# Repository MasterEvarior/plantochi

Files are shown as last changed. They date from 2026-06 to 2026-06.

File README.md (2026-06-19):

# Plantochi

> [!IMPORTANT]
> This project was done during a school workshop, so it will not be maintained.

A [Tamagotchi](https://de.wikipedia.org/wiki/Tamagotchi) but for your plants!

See the guide [here](https://masterevarior.github.io/plantochi/).

## Development

### Git hooks

The repository ships two git hooks under `.githooks/`:

- `commit-msg` — validates that commit messages conform to the Conventional
  Commit format.
- `pre-commit` — runs `nix flake check` before each commit.

When you enter the dev shell (`nix develop`), the hooks are wired up
automatically via `git config core.hooksPath .githooks/`.

### direnv

If you have [direnv](https://direnv.net/) installed, the dev shell is loaded
automatically when you enter the directory:

```sh
direnv allow
```

### Commands

Run to see a list of all available commands:

```shell
just
```

## AI Disclaimer

OpenCode BigPickle was used to generate an initial version of this `README.md` and some parts of the documentation.

## License

MIT

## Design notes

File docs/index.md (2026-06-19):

# Plantochi

Plantochi is a [Tamagotchi](https://de.wikipedia.org/wiki/Tamatchi) but for your plants!

- [Guide](guide.md){step}
- [Journey](journey.md){step}

Plantochi shows with unique facial expression the current crucial way that their owner lets them die with.
An example is linked below where the plan is thirsty and too hot.



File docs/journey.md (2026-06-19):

# Journey

## Day 1

On day 1, we only had a short brainstorming session. See the results below.

### Brainstorming

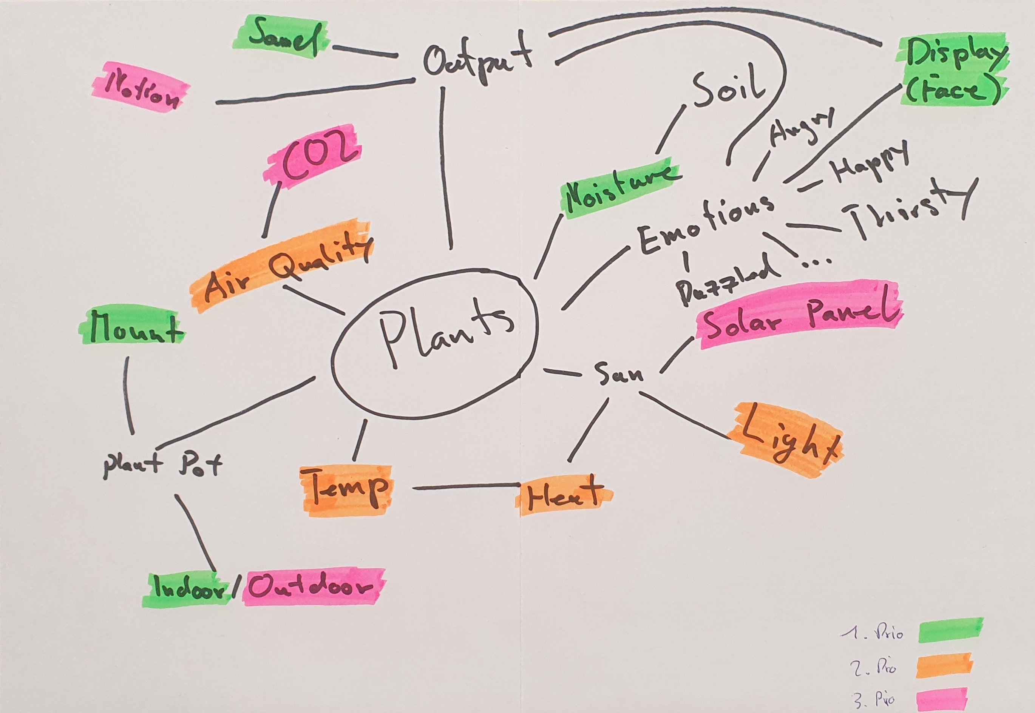
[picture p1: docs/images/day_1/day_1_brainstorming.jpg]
A piece of paper with brainstorming arround plants


From a first brainstorming session, we identified different things, with different priorities.
We decided on three priorities, with the following features:

| Priority (High to Low) | Features |
|-|-|
| 1 | Display and sound as output. Soil moisture sensor. Indoor only. |
| 2 | Air, temperature, light sensors in addition. |
| 3 | Motion (e.g. vibrating) as another way to get attention. A solar panel as energy source. Also rated for outdoor use.|

## Day 2

Creation of the first proof of concept (PoC) and prototypes. We also thought about how we can and should display the values to a user.

### Prototype Box

The first cardboard prototype was essentially a big box, with two hooks to put it onto a flower pot. The MCU (microcontroller unit) is placed towards the bottom so that the charging port can be placed below the box, together with the speaker which is hidden there. The display, light sensor and cables to extend to the soil moisture sensor are placed on the top.

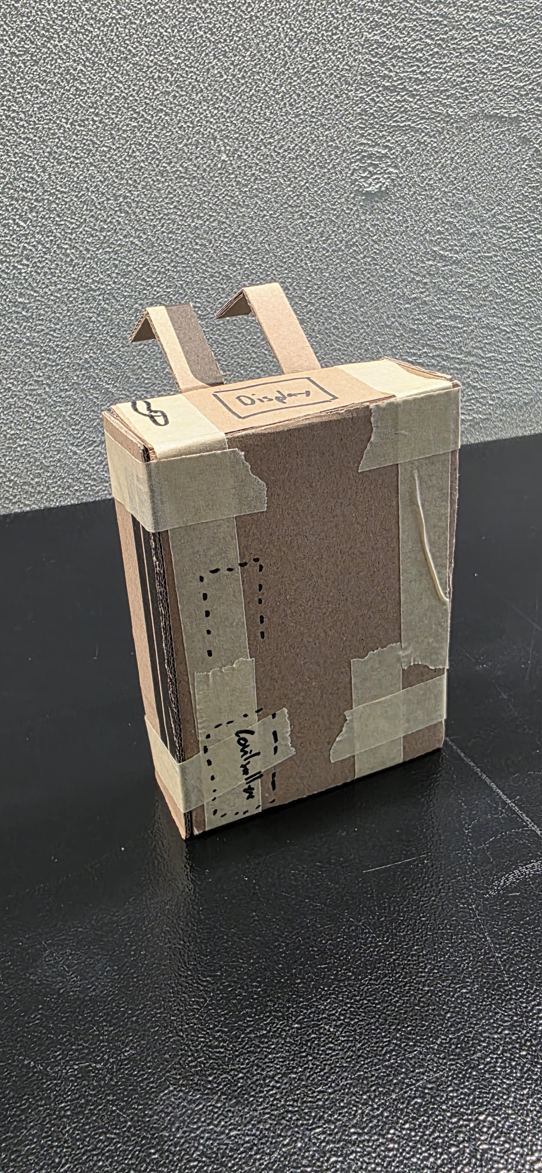
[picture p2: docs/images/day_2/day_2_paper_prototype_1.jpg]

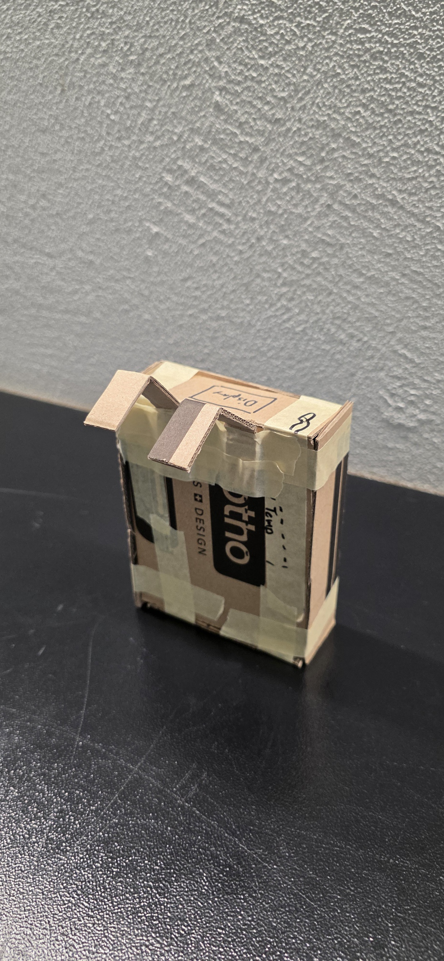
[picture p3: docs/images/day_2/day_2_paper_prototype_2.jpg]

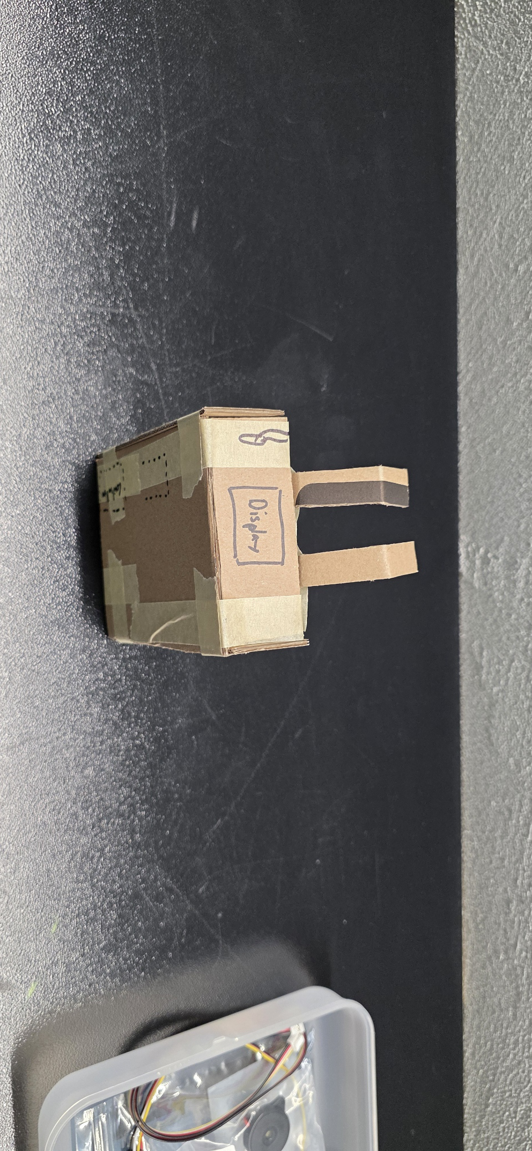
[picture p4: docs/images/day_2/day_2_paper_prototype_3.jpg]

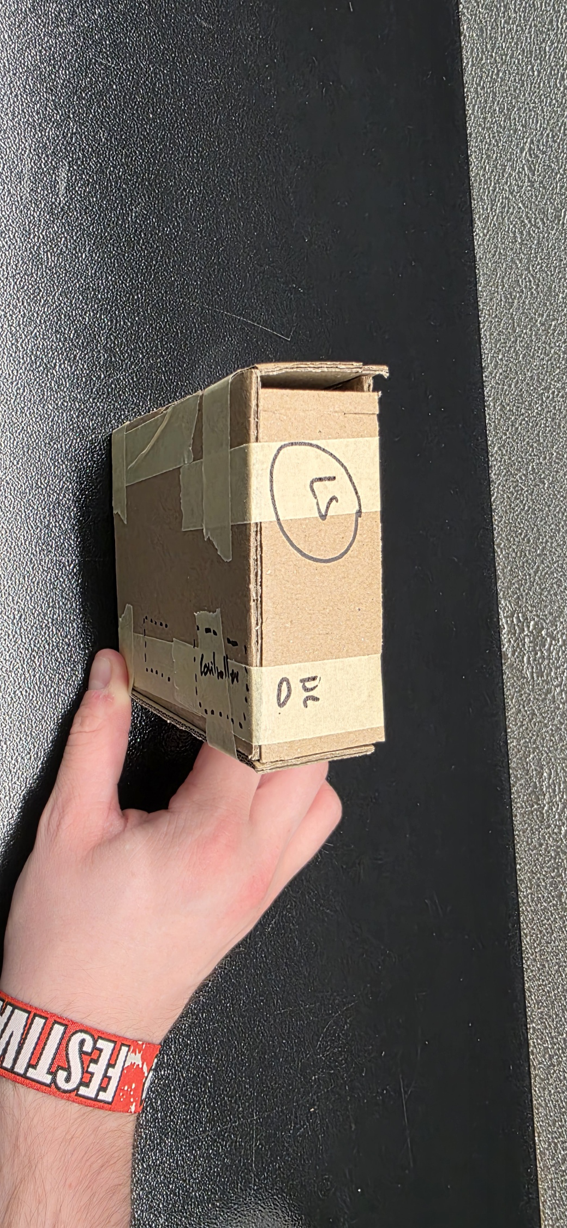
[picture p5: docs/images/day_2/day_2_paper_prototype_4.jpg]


### UI (Emotions)

Emotions are used to communicate with the user. Emotions like too bright or dark are naturally exclusive with each other. The following emotions are possible:

- Thirsty or waterlogged
- Too bright or dark
- Too hot or cold

The OLED displaying a face will be used to express the emotions.

| Sensors | Display |
|---|---|
| Thirsty | Open Mouth |
| Waterlogged | Sad Mouth |
| Bright | Squinted Eyes or Sunglasses |
| Dark | Big Eyes with huge pupils |
| Hot | Waves (like the ones on heaters) |
| Cold | Snowflake |

If two emotions concur at the same time, or it is "Thirsty", a piezo will be activated to cause sleepless nights.

### PoC

### Code

You can see the code for the first prototype [here](../code/poc_1/poc_1.ino).

#### Sketch of the PoC

A first sketch of the prototype is displayed below.
It is used to get some sense of what components we need and a bit on how they are supposed to be wired up.

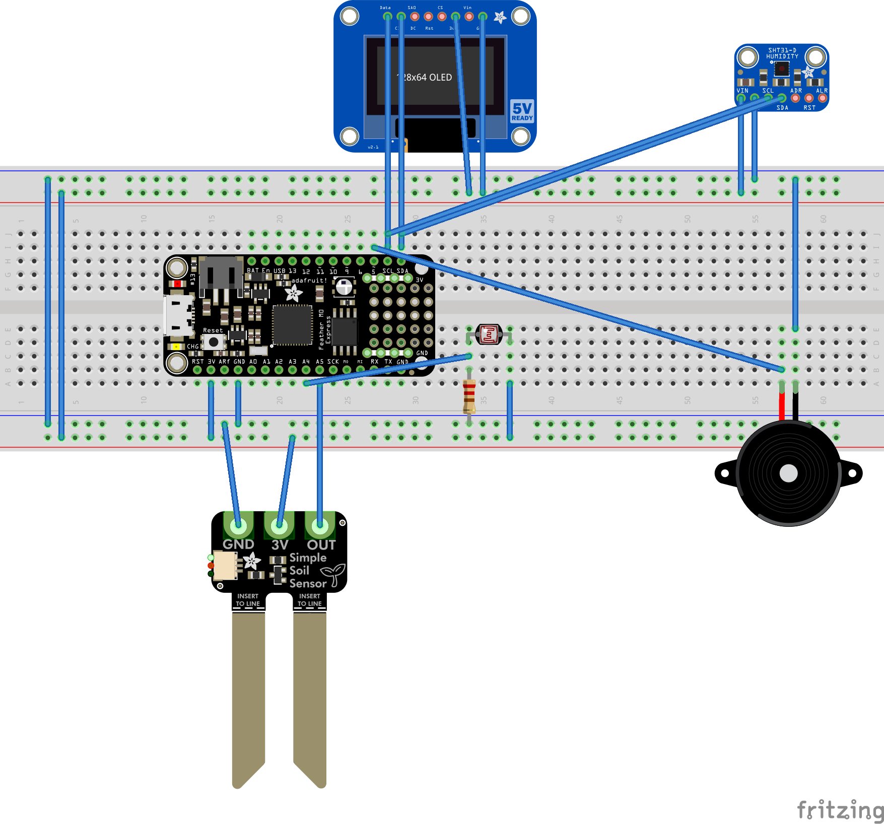
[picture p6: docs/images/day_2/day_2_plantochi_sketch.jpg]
Breadboard sketch of platochi in Fritzing


As there are about three craploads of components, we went on an expedition with our shovels and pickaxes and selected the components according to our plan.

#### Pinout

Description and more details: [https://learn.adafruit.com/adafruit-feather-m4-express-atsamd51/pinouts](https://learn.adafruit.com/adafruit-feather-m4-express-atsamd51/pinouts)

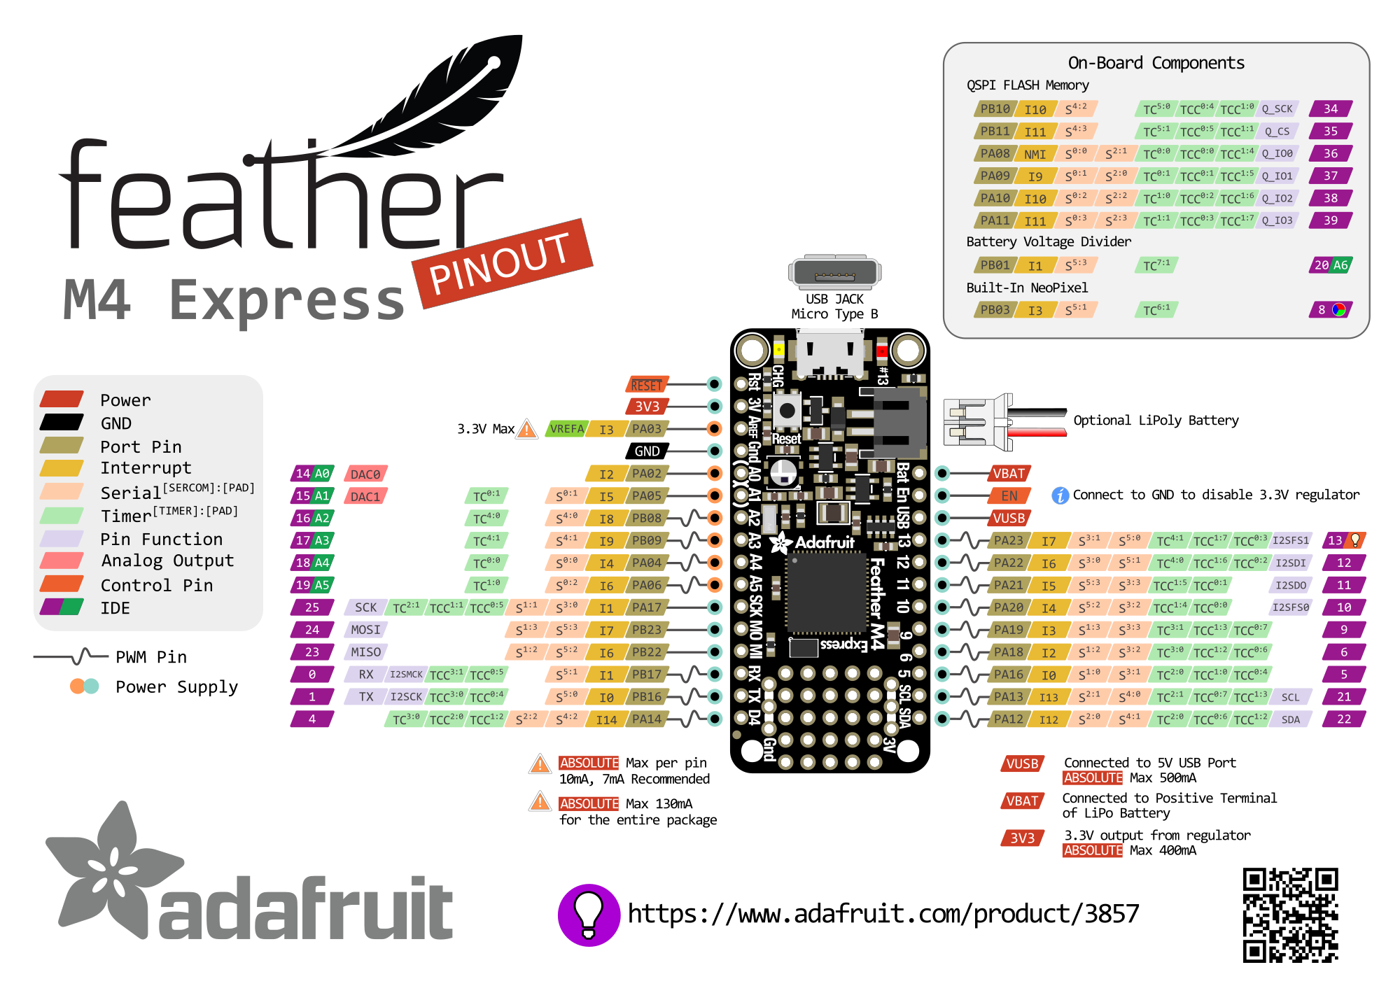
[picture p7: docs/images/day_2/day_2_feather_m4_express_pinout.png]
Pinout schematic for Feather M4 Express


## Day 3

Today was mostly spent finishing up the code and designing the enclosure.

### Code

The code was split in multiple files to make it *somewhat* more manageable. This brought the core loop to look like this:

```{.c}
void loop(void) {
  int badStates = 0;
  bool isThirsty = 0;

  Symbol symbol = Symbol::NONE;
  Eyes eyes = Eyes::NORMAL;
  Mouth mouth = Mouth::HAPPY;

  float light = readSensor(LIGHT);
  if(light > L_THRESHOLD_HIGH){
    eyes = Eyes::SQUINT;
    badStates++;
  } else if (light < L_THRESHOLD_LOW){
    eyes = Eyes::BIG;
    badStates++;
  } else {
    eyes = Eyes::NORMAL;
  }

  float airTemp = readSensor(AIR_TEMPERATURE);
  if(airTemp > T_THRESHOLD_HIGH){
    badStates++;
    symbol = Symbol::HEAT;
  } else if (airTemp < T_THRESHOLD_LOW){
    badStates++;
    symbol = Symbol::COLD;
  } else {
    symbol = Symbol::NONE;
  }

  // The value of the moisture sensor decreases
  // as the moisture increases
  float soilMoisture = readSensor(SOIL_MOISTURE);
  if(soilMoisture > M_THRESHOLD_HIGH){
    badStates++;
    isThirsty = 1;
    mouth = Mouth::OPEN;
  } else if (soilMoisture < M_THRESHOLD_LOW){
    badStates++;
    mouth = Mouth::SAD;
  } else {
    mouth = Mouth::HAPPY;
  }

  displayClear();
  displaySmiley(symbol, eyes, mouth);
  String text = getText(badStates);
  displayText(text.c_str());
  displayShow();

  if((isThirsty || badStates > 1) && !isBeeping){
    startBeep();
  } else {
    stopBeep();
  }

  updateBeep();

  // Cooldown
  delay(1500);
}
```

You can see the entire code under `/code/prod/`.

### Enclosure

The plantochi should be usable for all kinds of plants.
Some of these plants generate produce.
The PLA that is used in the schools’ 3D-printers, is not particularly food safe.
Therefore, wood was used for the box which is laser cut from sheets.

V1 schema for box

After laser cutting the box was assembled and held together by strong willpower, prayers and some tape.

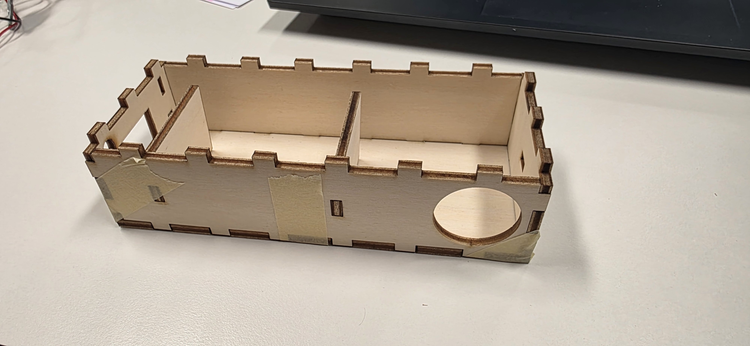
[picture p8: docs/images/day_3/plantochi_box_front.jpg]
Assembled box front

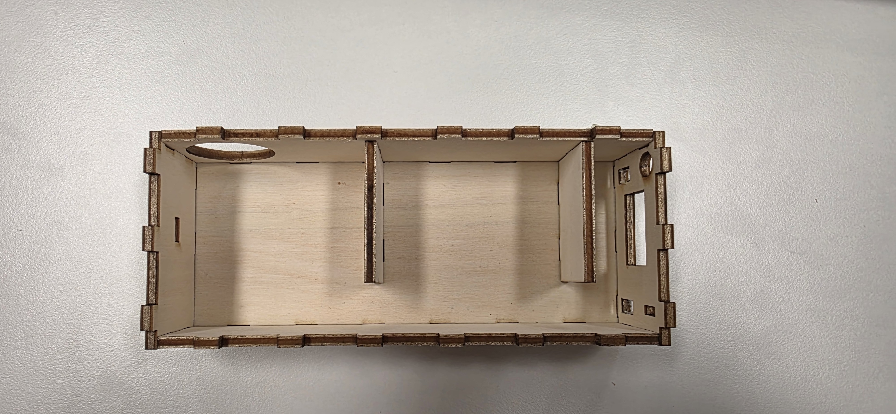
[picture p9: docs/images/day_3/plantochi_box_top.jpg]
Assembled box top


Some details were noticed when putting the components into the box:

- The cable for the display is very short and needs to reach very far
  - Moving the display slot a bit over
  - Switching the orientation for the box so that the display points the right way (parts of the display are blue and 
    yellow and this needs to face the right direction).
- Increase the size for the soil moisture sensor cable.
- Decrease the size for the LDR sensor (must have been drunk while measuring that).
- Adding a little hole in the wall for the battery.
- Increasing the size for the charging cable (those suckers are huge).

V2 schema for box

After planning all the details and creating different mount options (based on flower pot sizes), the **Next Gen Box 2.0** 
is released.
The **Next Gen Box 2.0** comes without any problems and can actually be used with the selected components.
Some wood glue and tape later, it is assembled and ready for tomorrow's hot glue day, where we make fit everything in 
the box.

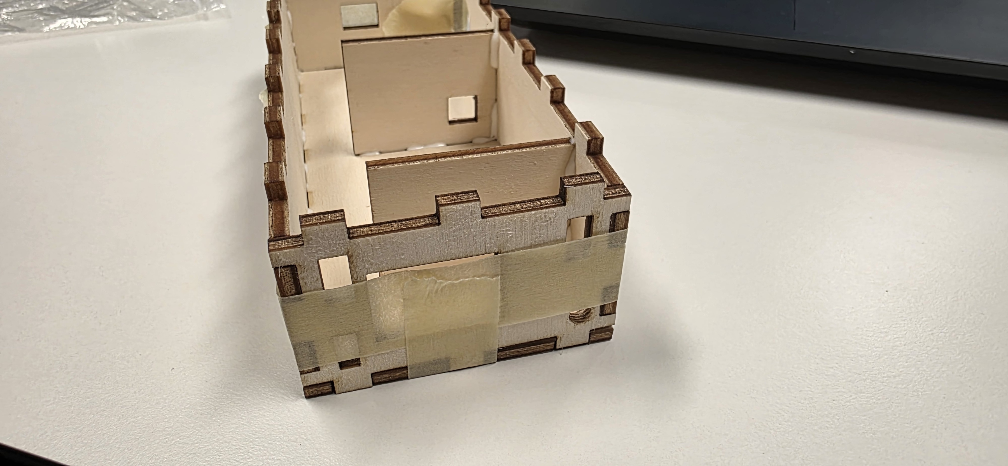
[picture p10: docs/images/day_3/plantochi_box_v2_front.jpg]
Assembled box v2 front

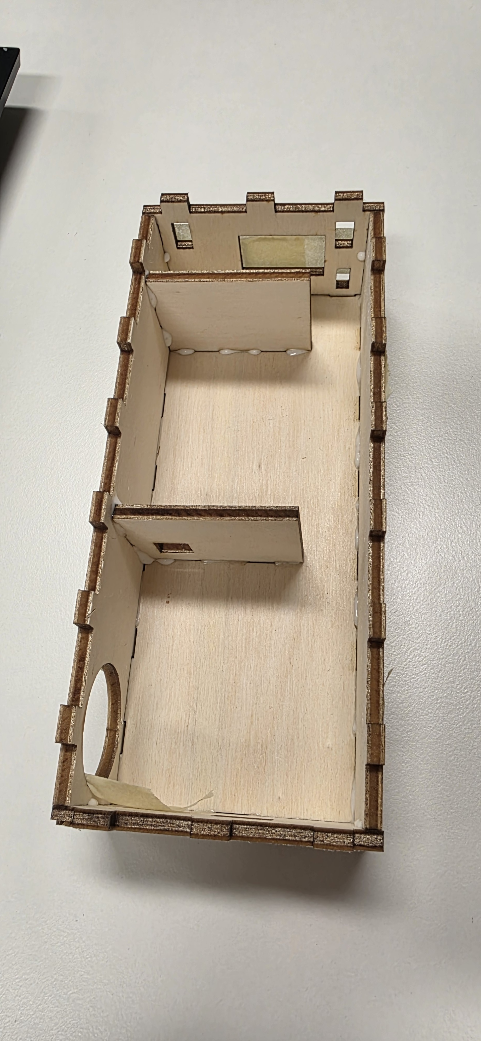
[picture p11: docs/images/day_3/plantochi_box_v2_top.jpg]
Assembled box v2 top


This box fits all the components and can therefore be used.

### Assembly

The box is fitted with all the components.
Some of them fit quite tightly into the box (like the Piezo), others are more loose (like the MCU).
To have everything fixed and to prevent any random failures due to movements in the box, an unhealthy amount of hot
glue is used.
In German there is a good saying for this: "Viel hilft viel".
Literally translated, it means "a lot helps a lot".
It is mostly used with irony and goes a bit into the opposite of "the more, the merrier".
Anyway, most parts will not move anymore.
The hot glue made sure of it.

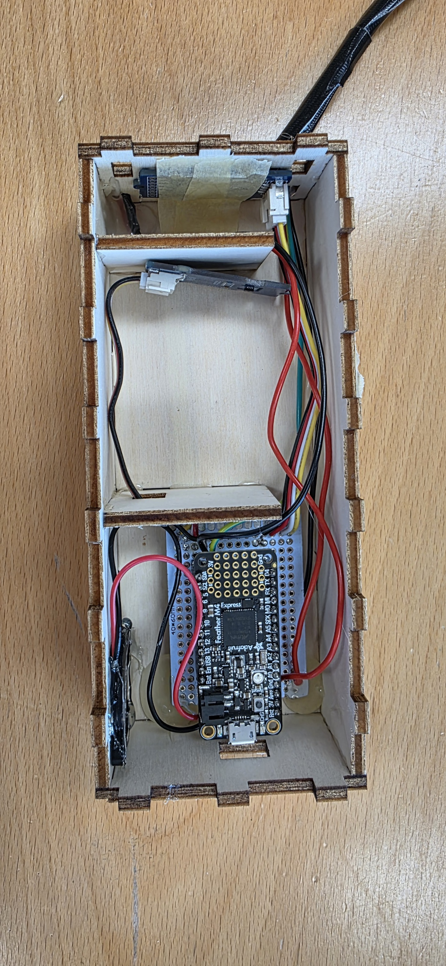
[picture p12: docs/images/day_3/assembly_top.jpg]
Assembled from top

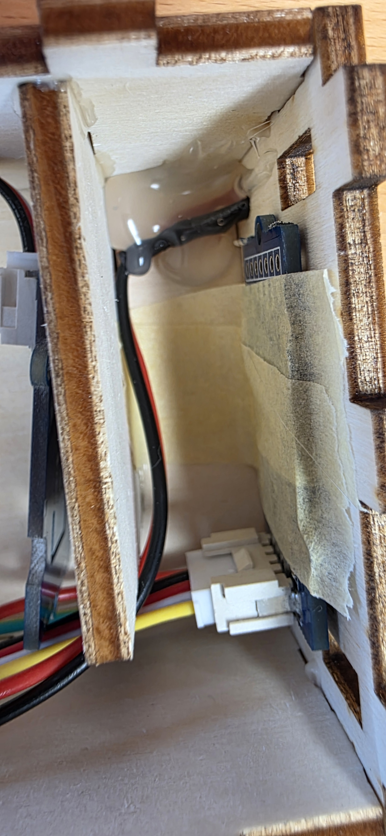
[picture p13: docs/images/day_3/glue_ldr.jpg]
Glue on LDR

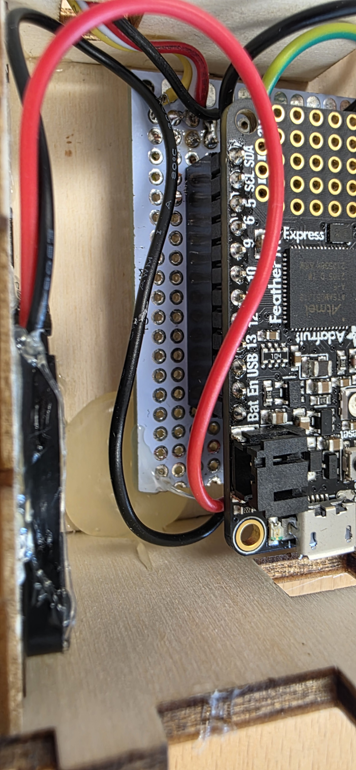
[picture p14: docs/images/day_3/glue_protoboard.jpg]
Glue on protoboard


Now, the logic was tested multiple times before putting everything in the box.
It was tested again after putting it into the box.
After hot gluing everything in place and having everything at their definite location, everything was tested again.
Two heart attacks later, checking the soldering lines was in order.
The symptom was a non-working OLED display.
There are four cables coming from the display: Ground, VCC, SCL, SDA.
Best if we check with a multimeter, if everything is still connected.
Given that the other components that were visible/audioable were still working, the code was most likely fine (there
were no changes anyway).
To check if every connection is fine, one can start checking that there is a connection between every cable (1,2,3,4)
and their appropriate counterpart (5,6,7,8).
The expected outcome is the following connections:
1 → 7 (clock),
2 → 8 (data),
3 → 5 (VCC),
4 → 6 (GND).

Image with numbers to show debugging

Turns out, all the connections are fine like that.
The next thing is checking for shorts.
Turns out data and VCC are connected somewhere.
At first this made little sense, as the soldering for the OLED display looks good.
There is a second connection on the same IC2 connection, though.
The one for the temperature and humidity sensor.
As you already can guess, the cables there were touching.
Bending the cables back into shape and, while monitoring that the display keeps working, hot gluing everything, solved
the problem.

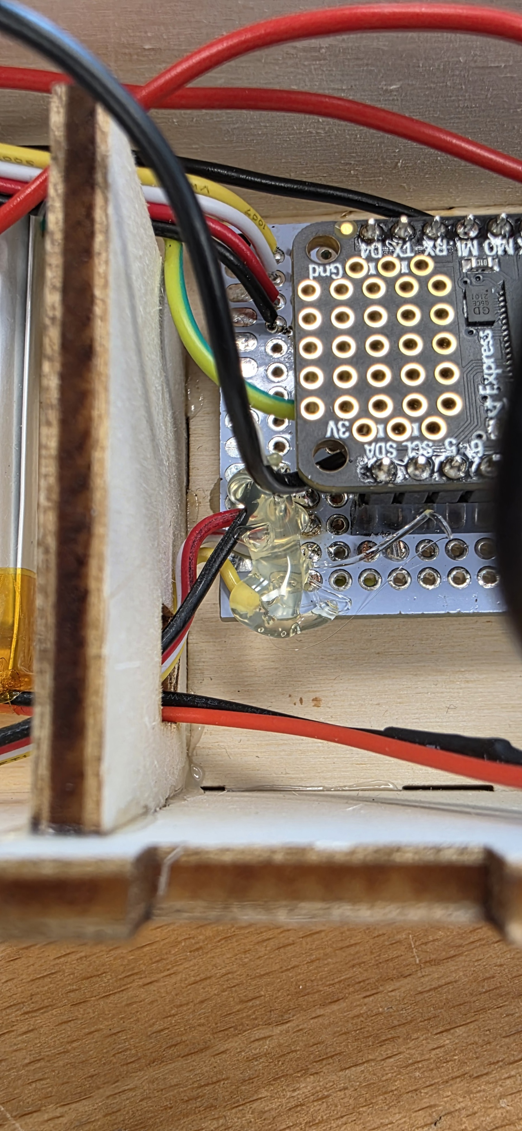
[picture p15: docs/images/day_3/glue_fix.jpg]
Image with hotglued connection isolation


Lesson learned: Apparently, if you crunch a couple of cables around a corner, and their uninsulated ends touch, half 
the project will not work anymore.

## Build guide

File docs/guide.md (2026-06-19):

# Guide

## Bill of Materials

{{BOM}}

## Guide

Here are the build steps:

- [Step 1: Install the software](./guide/software.md){step}
- [Step 2: Solder the parts together](./guide/soldering.md){step}
- [Step 3: Create the enclosure](./guide/enclosure.md){step}
- [Step 4: Final assembly](./guide/assembly.md){step}

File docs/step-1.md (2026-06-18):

# Install the Software

{{BOM}}

## Setup Arduino IDE {pagestep}

Install the [Arduino IDE](https://www.arduino.cc/en/software/) for your operating system. Also be sure to install the following libraries:

- [Adafruit SHT31](https://github.com/adafruit/Adafruit_SHT31)
- [U8g2](https://github.com/olikraus/u8g2)

Next, add the Adafruit board support to your Arduino IDE. Open **File → Preferences** and add the following URL to the *Additional Boards Manager URLs* field:

```
https://adafruit.github.io/arduino-board-index/package_adafruit_index.json
```

Then open **Tools → Board → Boards Manager**, search for `Adafruit Feather M4` and install the **Adafruit SAMD Boards** package.

## Install the code {pagestep}

Connect your [Feather M4 Express]{Qty: 1} to your laptop using a [USB A (or C) to micro USB cable]{Qty: 1, Cat: Tool}.
Download the code from `code/prod/` and open the `prod.ino` file in the Arduino IDE.

Select your board: go to **Tools → Board → Adafruit SAMD Boards → Adafruit Feather M4 Express**.
Select the port: **Tools → Port → (the port your Feather is connected to)**.

Finally, click the **Upload** button (right arrow icon) or press **Ctrl+U** to compile and flash the code onto your Feather M4.

[Feather M4 Express]: Parts.yaml#FeatherM4
[USB A (or C) to micro USB cable]: Parts.yaml#USBMicroCable

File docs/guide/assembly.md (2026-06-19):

# Assembly

{{BOM}}

## Place the electronics in the box {pagestep}

Fit the protoboard and sensors into [the created enclosure](./enclosure.md). Connect the [LiPo Battery]{Qty: 1} to the Feather M4 and tuck it into the middle compartment. Route the [USB A (or C) to micro USB cable]{Qty: 1, Cat: Tool} through the charging port hole. Make sure the OLED display sits flush in its slot and the soil moisture sensor cable exits through its opening.

## Hot glue everything in place {pagestep}

Use a [Hot Glue Gun]{Qty: 1, Cat: Tool} to secure the protoboard, sensors, and cables inside the box. Apply glue to the corners of the components and hold them in place until the glue sets. Avoid getting glue on connectors or the display.






## Close the box {pagestep}

Press the lid on firmly. We recommend not using any glue here, so you can open it up later on.

## Final test {pagestep}

Power on the Plantochi. Check that the display lights up, the sensors report readings, and the piezo buzzer works. Place the moisture sensor in soil and verify the display reacts to changes.

[LiPo Battery]: ../Parts.yaml#LiPoBattery
[Hot Glue Gun]: ../Parts.yaml#HotGlueGun
[Wood Glue]: ../Parts.yaml#WoodGlue
[USB A (or C) to micro USB cable]: ../Parts.yaml#USBMicroCable

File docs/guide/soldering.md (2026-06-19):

# Solder

{{BOM}}

## Prepare your workspace {pagestep}

Set up your [Soldering Iron]{Qty: 1, Cat: Tool}, [Solder Wire]{Qty: 1, Cat: Tool}, and [Protoboard]{Qty: 1}. Make sure you have good ventilation (or simply do not care enough for the consequences).

## Solder headers to the Feather M4 {pagestep}

Insert your [Pin Headers]{Qty: 2} into the Feather M4's through-holes. Flip the board over and solder each pin, making sure the headers sit straight and do not touch each other.

## Solder the sensor wires {pagestep}

Cut and strip lengths of [Hook-up Wire]{Qty: 1, Cat: Tool} to connect the [Piezo Buzzer]{Qty: 1}, [LDR Light Dependent Resistor]{Qty: 1}, [Grove Capacitive Moisture Sensor]{Qty: 1}, [OLED Display]{Qty: 1}, and [Temperature Humidity Sensor]{Qty: 1} to the protoboard.

>! **Attention** 
>! 
>! Make the wire rather **too long** than **not long enough**.
>! The case as more than enough space to hide them all.

## Connect everything on the protoboard {pagestep}

Solder the wires and pin headers from the Feather M4 to the [Protoboard], routing the connections to each sensor. Double-check your pinout before soldering each joint.

## Test your soldering {pagestep}

Visually inspect all solder joints for cold joints or bridges. You should also be able to see the readings for each sensonr, aswell as something on the display, if you already installed the software from [the step before](software.md).

[Soldering Iron]: ../Parts.yaml#SolderingIron
[Solder Wire]:  ../Parts.yaml#SolderWire
[Pin Headers]:  ../Parts.yaml#HeaderPins
[Protoboard]:  ../Parts.yaml#ProtoBoard
[Hook-up Wire]:  ../Parts.yaml#Wire
[Piezo Buzzer]:  ../Parts.yaml#PiezoBuzzer
[LDR Light Dependent Resistor]:  ../Parts.yaml#LDR
[Grove Capacitive Moisture Sensor]:  ../Parts.yaml#GroveCapMoistSensor
[OLED Display]:  ../Parts.yaml#OledDisplay
[Temperature Humidity Sensor]:  ../Parts.yaml#TempHumiSensor

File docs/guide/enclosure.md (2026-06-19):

# Cut the enclosure

{{BOM}}

## Download the necessary files {pagestep}

Download the files:

- [plantochi_box.svg](../images/day_3/plantochi_box.svg)
- [plantochi_box_v2.svg](../images/day_3/plantochi_box_v2.svg)

>i **Note**
>i
>i Note that you need to download and cut **both** files.

## Make the laser cutter go BRRR {pagestep}

Take both files to your [laser cutter]{Qty: 1, Cat: Tool} and cut them from one [A4 plywood sheet]{Qty: 2} each.

## Glue everything together {pagestep}

Take some [wood glue]{Qty: 1, Cat: Tool} and glue everything together.




[A4 plywood sheet]:  ../Parts.yaml#Wood
[laser cutter]:  ../Parts.yaml#LaserCutter
[wood glue]:  ../Parts.yaml#WoodGlue

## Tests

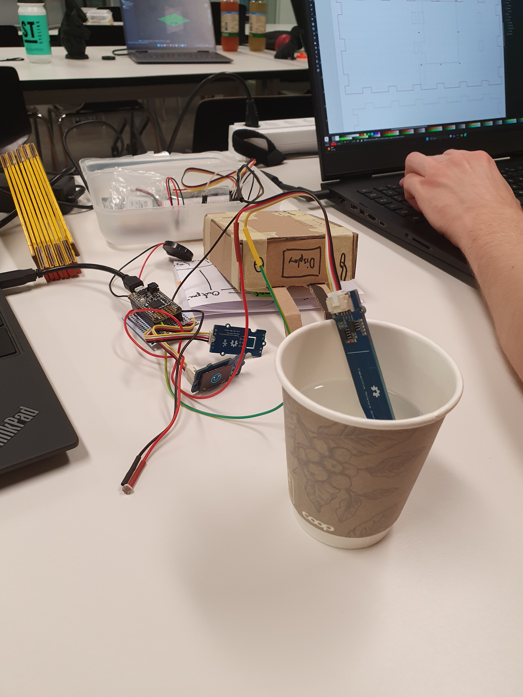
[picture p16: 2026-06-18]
docs/images/day_3/testing.jpg

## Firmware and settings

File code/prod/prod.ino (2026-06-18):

#include <Arduino.h>
#include <U8g2lib.h>
#include <Wire.h>
#include "Adafruit_SHT31.h"

#ifdef U8X8_HAVE_HW_SPI
#include <SPI.h>
#endif
#ifdef U8X8_HAVE_HW_I2C
#include <Wire.h>
#endif

/*
  Variables to adjust
*/

#define SHT_ADDR 0x44
#define LS_PIN 5
#define MOISTURE_PIN A5
#define LDR_PIN A4

#define M_THRESHOLD_LOW 400
#define M_THRESHOLD_HIGH 600
#define T_THRESHOLD_LOW 15
#define T_THRESHOLD_HIGH 30
#define L_THRESHOLD_LOW 200
#define L_THRESHOLD_HIGH 600


/*
  Keep this as is
*/

enum Sensor {
  LIGHT,
  SOIL_MOISTURE,
  AIR_TEMPERATURE,
  AIR_MOISTURE
};

enum class Eyes {
  NORMAL,
  SQUINT,
  BIG
};

enum class Mouth {
  HAPPY,
  SAD,
  OPEN
};

enum class Symbol {
  NONE,
  HEAT,
  COLD,
};

U8G2_SSD1306_128X64_NONAME_F_HW_I2C u8g2(U8G2_R0, SCL, SDA, U8X8_PIN_NONE);
Adafruit_SHT31 sht31 = Adafruit_SHT31();
unsigned long toneStartTime = 0;
bool isBeeping = false;
int messageState = 0;

void setup(void) {
  Serial.begin(115200);

  sht31.begin(SHT_ADDR);
  u8g2.begin();

  displayClear();
  displayText("Initializing...");
  displayShow();
  delay(1000);
}

void loop(void) {
  int badStates = 0;
  bool isThirsty = 0;

  Symbol symbol = Symbol::NONE;
  Eyes eyes = Eyes::NORMAL;
  Mouth mouth = Mouth::HAPPY;

  float light = readSensor(LIGHT);
  if(light > L_THRESHOLD_HIGH){
    eyes = Eyes::SQUINT;
    badStates++;
  } else if (light < L_THRESHOLD_LOW){
    eyes = Eyes::BIG;
    badStates++;
  } else {
    eyes = Eyes::NORMAL;
  }

  float airTemp = readSensor(AIR_TEMPERATURE);
  if(airTemp > T_THRESHOLD_HIGH){
    badStates++;
    symbol = Symbol::HEAT;
  } else if (airTemp < T_THRESHOLD_LOW){
    badStates++;
    symbol = Symbol::COLD;
  } else {
    symbol = Symbol::NONE;
  }

  // The value of the moisture sensor decreases
  // as the moisture increases
  float soilMoisture = readSensor(SOIL_MOISTURE);
  if(soilMoisture > M_THRESHOLD_HIGH){
    badStates++;
    isThirsty = 1;
    mouth = Mouth::OPEN;
  } else if (soilMoisture < M_THRESHOLD_LOW){
    badStates++;
    mouth = Mouth::SAD;
  } else {
    mouth = Mouth::HAPPY;
  }

  displayClear();
  displaySmiley(symbol, eyes, mouth);
  String text = getText(badStates);
  displayText(text.c_str());
  displayShow();

  if((isThirsty || badStates > 1) && !isBeeping){
    startBeep();
  } else {
    stopBeep();
  }

  updateBeep();

  // Cooldown
  delay(1500);
}

String getText(int amount){
  if(amount == 0){
    return "";
  }

  if(messageState == 0){
    messageState = 1;
    return "Bad plant parent!";
  } else if(messageState == 1 && amount != 1){
    messageState = 0;
    String suffix = " things are wrong!";
    return amount + suffix;
  } else if(messageState == 1 && amount == 1){
    messageState = 0;
    String suffix = " thing is wrong!";
    return amount + suffix;
  } 

  return "";
}

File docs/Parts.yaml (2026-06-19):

---
PiezoBuzzer:
    Name: Piezo Buzzer
    Description: >
        A piezo buzzer element for sound generation in electronics projects.
    Specs:
        "Rated Voltage (Square Wave)": 12Vp-p
        "Operating Voltage": 1 - 30Vp-p
        "Rated Current (MAX)": 3.5mA
        "Min. Sound Output at 10cm": 85db
        "Resonant Frequency": 1300Hz ± 500 / 4000Hz ± 500
        "Operating Temperature": -20 - 60 °C
        Diameter: 30mm
        "Mounting Hole Width": 41mm
        "Center Diameter": 5.7mm
        Weight: 4.3g
    Suppliers:
        Adafruit:
            Link: https://www.adafruit.com/product/1739
            PartNo: 1739
LDR:
    Name: LDR Light Dependent Resistor
    Description: >
        A light dependent resistor (photoresistor) whose resistance decreases with increasing incident light intensity.
    Specs:
        Type: GL5528
        "Max Voltage (DC)": 150V
        "Max Power": 100 mW
        "Operating Temperature": -30 - 70 °C
        "Peak Spectral Response": 540 nm
        "Dark Resistance": 1 MΩ (min)
        "Light Resistance": 10-20 kΩ (at 10 Lux)
    Suppliers:
        AliExpress:
            Link: https://de.aliexpress.com/item/1005011864778977.html
            PartNo: GL5528
GroveCapMoistSensor:
    Name: Grove Capacitive Moisture Sensor (Corrosion Resistant)
    Description: >
        The Grove - Capacitive Moisture Sensor (Corrosion Resistant) is a soil moisture sensor based on capacitance changes.
        Compared with resistive sensors, capacitive sensors do not require direct exposure of the metal electrodes,
        which can significantly reduce the erosion of the electrodes. Hence, we call it Corrosion Resistant.
    Specs:
        "Operating Voltage": 3.3V / 5V
        "Output Interface": Analog
        Length: 92.1mm
        Width: 23.5mm
        Height: 6.5mm
        Weight: 10.6g
    Suppliers:
        SeedStudio:
            Link: https://www.seeedstudio.com/Grove-Capacitive-Moisture-Sensor-Corrosion-Resistant-p-2580.html
            PartNo: SH1107
OledDisplay:
    Name: Geekcreit 0.96 inch 4 pin white I2C OLED
    Description: >
        The SSD1306 is a 0.96-inch monochrome OLED display that communicates over I2C using just two wires — SDA and SCL.
        It is one of the most commonly used displays in Arduino projects because of its sharp 128x64 pixel output, ultra-low power draw, and wide library support.
    Specs:
        "Display Size": 0.96 inches (measured diagonally)
        Resolution: 128x64 pixels
        Driver IC: SSD1306
        Interface Type: I2C (can also be SPI on some modules)
        Operating Voltage: 3.3V to 5V
        Viewing Angle: Nearly 180 degrees
        Color: Typically monochrome
    Suppliers:
        AliExpress:
            Link: https://de.aliexpress.com/s/wiki-ssr/article/geekcreit-0.96-inch-oled-i2c-iic-communication-display-128-64-lcd-module-geekcreit-products-info-and-review
            PartNo: HD44780
GroveOledDisplay:
    Name: Grove OLED Display 0.96 inch
    Description: >
        Grove - OLED Display 0.96" module is an OLED monochrome 128x64 dot matrix display module
        with Grove 4pin I2C Interface. It has bigger screen so that it can display more contents
        than the OLED 96x96.
    Specs:
        "Display Size": 0.96 inches
        Resolution: 128x64 pixels
        Driver IC: SSD1308Z
        Interface Type: I2C
        Operating Voltage: 3.3V - 5.5V
        Display Color: White
        I2C Address: 0x3C
        Panel Size: 26.7(W)x19.26(H) mm
        Active Area: 21.74(W)x11.175(H) mm
        Operating Temperature: -20 - 70 °C
    Suppliers:
        SeedStudio:
            Link: https://www.seeedstudio.com/Grove-OLED-Display-0.96%26quot%3B-p-781.html
            PartNo: 104030002
USBMicroCable:
    Name: USB-A to Micro USB Cable
    Description: >
        A standard USB 2.0 A to Micro-USB B cable for powering and programming
        microcontroller boards such as Feather, Arduino, and similar development boards.
    Specs:
        Connector A: USB-A or C
        Connector B: Micro-USB
LaserCutter:
    Name: Laser Cutter
    Description: >
        A machine that can cut wood with shiny light. We used a Trotec Q400 but it will probably work with a much less expensive one.
SolderingIron:
    Name: Soldering Iron
    Description: >
        A soldering iron with a fine tip for soldering through-hole components and headers.
SolderWire:
    Name: Solder Wire
    Description: >
        Lead-free solder wire for electronics soldering.
HeaderPins:
    Name: Pin Headers
    Description: >
        Breakaway male pin headers for soldering to the Feather M4 and other boards.
LiPoBattery:
    Name: LiPo Battery
    Description: >
        A 3.7V LiPo battery for powering the Plantochi. Fits inside the enclosure and connects to the Feather M4's built-in charger.
HotGlueGun:
    Name: Hot Glue Gun
    Description: >
        A hot glue gun for securing components and wires inside the enclosure.
WoodGlue:
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

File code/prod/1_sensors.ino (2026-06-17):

float readSensor(Sensor type) {
    float value = 0;

    switch(type) {
        case LIGHT:
            value = (float) analogRead(LDR_PIN);
            logSensor("Light", value);
            break;
        case SOIL_MOISTURE:
            value = (float) analogRead(MOISTURE_PIN);
            logSensor("Soil Moisture", value);
            break;
        case AIR_TEMPERATURE:
            value = sht31.readTemperature();
            logSensor("Air Temperature", value);
            break;
        case AIR_MOISTURE:
            value = sht31.readHumidity();
            logSensor("Air Humidity", value);
            break;
    }
    
    return value;
}

void logSensor(String label, float value) {
  Serial.print(label);
  Serial.print(": ");
  Serial.println(value);
}

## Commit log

2026-06-17 docs: add emotions and sketches for prototypes
    [sketch.fzz]
2026-06-17 docs: add more details about cardboard prototype and the used code
2026-06-18 feat: add amazing doc for the enclosure
2026-06-19 feat: add doc about assembly and debugging
